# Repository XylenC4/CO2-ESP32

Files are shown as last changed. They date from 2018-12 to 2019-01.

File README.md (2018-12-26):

# CO2-ESP32
Arduino CO2 and Temperature logger based on BOSCH BME280 and Winsen MH-Z19B

## Functions
___
- Shows C02, Temperature, Humidity, Pressure
- Temperature (and humidity) can be corrected, if the BME280 if off calibration
- Thingspreak implementation including WiFi access

## Parts needed
___
- DOIT! ESP32 (any ESP32 should work, might not fit in the case)
- OLED 0.97" 128x64 Display
- MH-Z19B CO2 sensor
- BME280 sensor

    -> I'll had a 5V compatible version
    
    -> Make shure you connect it to 3.3V if you don't have

## Shematics
___
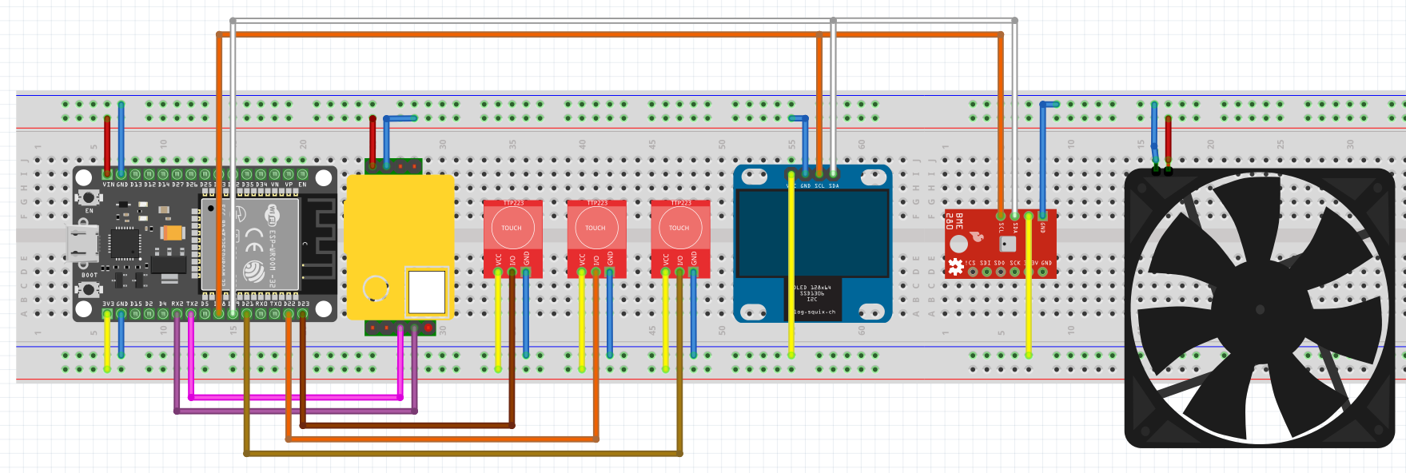
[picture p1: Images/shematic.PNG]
shematic


### User Interface
___
General Interface

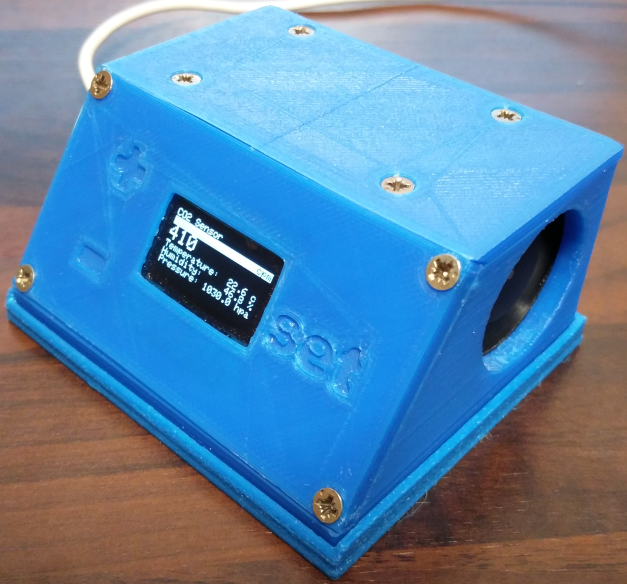
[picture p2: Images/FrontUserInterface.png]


### Log
___
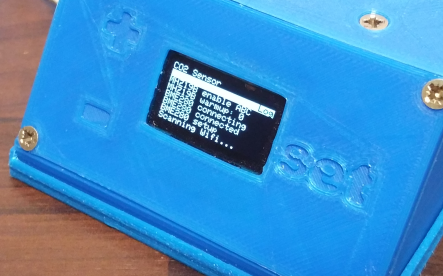
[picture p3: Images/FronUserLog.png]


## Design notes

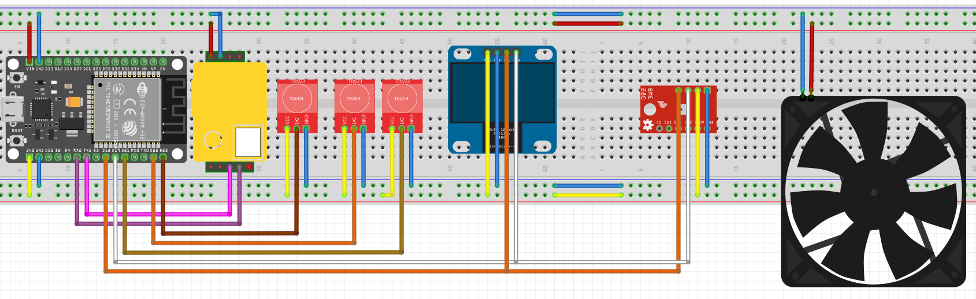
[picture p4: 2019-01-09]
Drawing/shematic.PNG

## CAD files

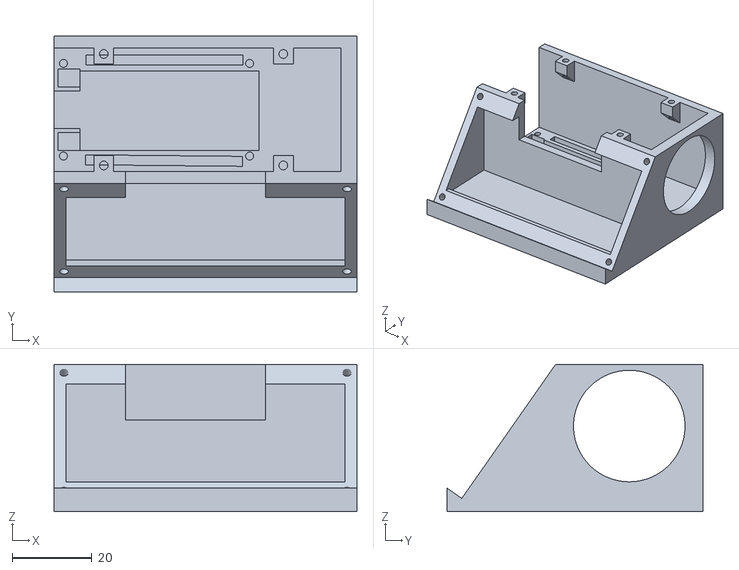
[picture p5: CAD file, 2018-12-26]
Drawing/ESP32.stl
76.1 x 64.3 x 37.0

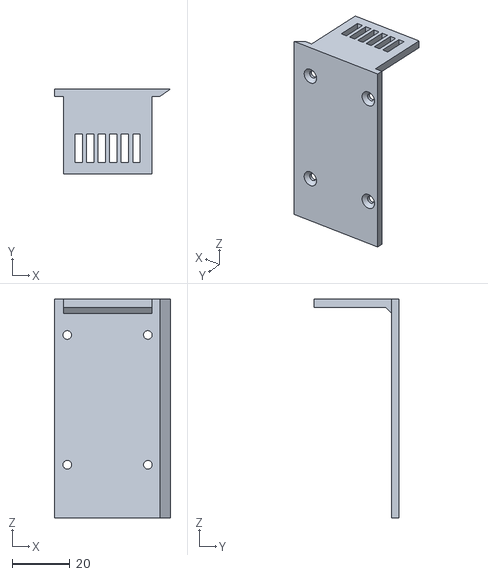
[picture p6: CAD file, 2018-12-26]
Drawing/Cover.stl
40.4 x 29.6 x 76.1

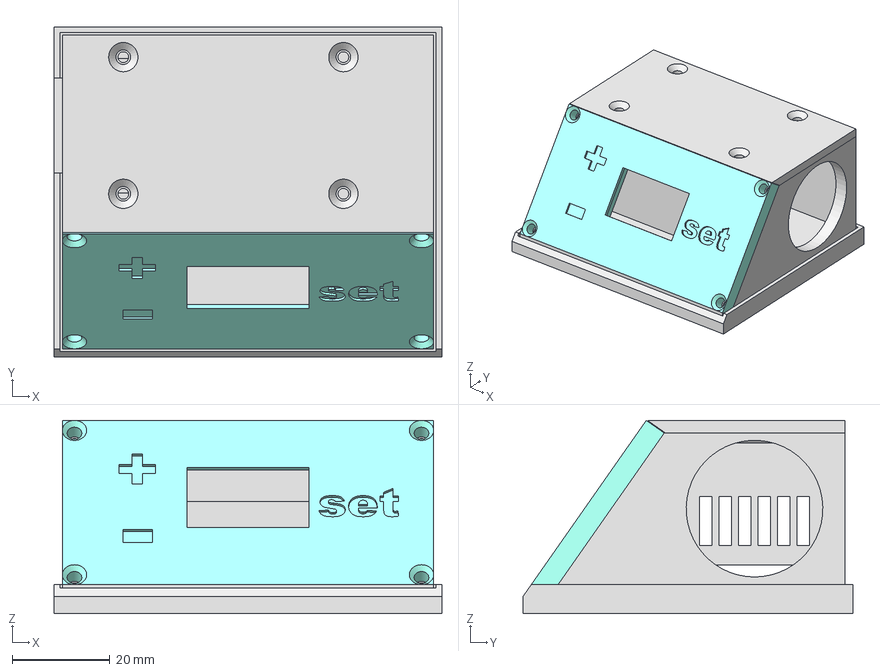
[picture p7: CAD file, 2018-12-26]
Drawing/Part.step
79.5 x 67.7 x 39.6 mm
ESP32
Case_base_v3
Cover
RubberCover

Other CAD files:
Drawing/Part.stl

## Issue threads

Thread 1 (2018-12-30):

Shema

Alfourbe, 2018-12-30:
Hi,
thank you fo sharing, I plan to make it and I ordered MHz19 sensor, meanwhile there is a little error in the schema, MHZ and OLED GND line are not connected to ground.

How do you power it? via USB?

Thanks

XylenC4, 2019-01-04:
Hey, yes USB power is good enough. I will check the "shematics" tomorrow. Thank you!

XylenC4, 2019-01-09:
i fixed it and some other things! Thanks you for your remarks.

Closed 2019-01-09.

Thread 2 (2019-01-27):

No much info

ffnull, 2019-01-27:
Hello. Im buy all needed components and print housing. But you doesnt provide much info. Withch libraries  to use? And other

XylenC4, 2019-01-27:
all of the used Arduino Libaries you can find on top of https://github.com/XylenC4/CO2-ESP32/blob/master/Arduino/CO2.ino

Adafruit_GFX
Adafruit_SSD1306
Adafruit_Sensor
Adafruit_Sensor

all the other are a part of the ESP32 Arduino enviroment.

ffnull, 2019-01-27:
D:\Downloads\CO2-ESP32-master\CO2-ESP32-master\Arduino\CO2\Thingspeak.ino: In function 'void loop_Thingspeak()':

D:\Downloads\CO2-ESP32-master\CO2-ESP32-master\Arduino\CO2\Thingspeak.ino:14:23: warning: unused variable 'SensorLoop' [-Wunused-variable]

   static unsigned int SensorLoop = 0;

                       ^

D:\Downloads\CO2-ESP32-master\CO2-ESP32-master\Arduino\CO2\TouchButton.ino: In function 'int CheckMenuOrder()':

TouchButton:46:1: error: no return statement in function returning non-void [-Werror=return-type]

 }

 ^

cc1plus.exe: some warnings being treated as errors

exit status 1
no return statement in function returning non-void [-Werror=return-type]

ffnull, 2019-01-27:
And. Please show the photo how you put everything inside.

XylenC4, 2019-01-27:
Make shure you have https://dl.espressif.com/dl/package_esp32_index.json inside the preferences and install "esp32" v1.0.0 or v1.0.1 at the board manager. Then you have to select the board "DOIT ESP32 DEVKIT V1"

Please try to rename the folder "Arduino" to "CO2" (which is the original name for the project)

XylenC4, 2019-01-27:
It's wired with 0.1 Header and soldered on the OLED & Touch Switches.
The sensors are glued with "hot snod".

https://github.com/XylenC4/CO2-ESP32/blob/master/Images/Wiring%201.jpg
https://github.com/XylenC4/CO2-ESP32/blob/master/Images/Wiring%202.jpg

ffnull, 2019-01-27:
All done. But still cant compile. Full log https://pastebin.com/0xugvqDd

XylenC4, 2019-01-27:
please update to Ardiono 1.8.8

ffnull, 2019-01-27:
When im compile CheckMenuOrder function. Its compiles

ffnull, 2019-01-27:
After flashing im got circle reboot with kernel panic

ffnull, 2019-01-27:
Please add zip archive with your libraries

XylenC4, 2019-01-27:
As requested: https://github.com/XylenC4/CO2-ESP32/tree/master/Arduino

ffnull, 2019-01-27:
Strange. My board esp32 core board v2. Your code still give kernel panic.
`Guru Meditation Error: Core  1 panic'ed (IntegerDivideByZero). Exception was unhandled.`
What can be wrong?

ffnull, 2019-01-27:
Any ideas?

XylenC4, 2019-01-27:
Because of some other projects with bluetooth i flashed a newer firmware (which helped with bluetooth) https://www.espressif.com/en/support/download/at

yours is "ESP32-WROVER" and can be flashed with https://github.com/espressif/esptool
On Windows you can use the esptool out of the Arduino Board Manager: %AppData%\..\Local\Arduino15\packages\esp32\tools\esptool_py\2.6.0

ffnull, 2019-01-31:
Hah. My chip is esp-wroom-32. going to flash correct firmware

ffnull, 2019-01-31:
Ok. Flash correct firmware. Then yours code. Still doesnt work

XylenC4, 2019-02-01:
you can try to compile it on another computer where Arduino never was installed.

Closed 2019-05-24.

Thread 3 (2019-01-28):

Question

Alfourbe, 2019-01-28:
Hi,
sorry to open an issue, I have just 2 questions but don not see how to ask without opening an issue.
I wonder if the fan could have an impact on the pressure reading in the box. Did you test with and without fan to check the difference?

I received my Mzh19 since, and I dont' want to keep the fan on all time. I will put a transistor to switch it on just one minute before reading co2 every 15-20 min, do you think it can be an issue with the reliability of co2 reading?
Thank you

Alfourbe, 2019-01-31:
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
FYI I finnally make it work, thanks to you, it was more complicated tha expected as I used parts I already have (ESP8266, BMP180... and I had to change and adapt all libraries but here we go
Happy :), thank to you

XylenC4, 2019-02-01:
nice to see you was able to run and modify it for ESP8266. I'll have some issues with a thermal drift which is caused by my ESP32. At the moment i do not use a deep sleep but this will be changed in the future. Have you done any tests regarding the pressure yet? There is no "warmup" time specified in the datasheet of the MH-Z19B.

Alfourbe, 2019-02-01:
HI, from l what I saw in the Datasheet, it is 3 min preheat time and response time less than 60sec, that's why I wanted to read pressure, switch on fan, wait 1 min, read CO2, and switch off fan.
I think I will also start WIFI only when connecting to Thingspeak, and switch it off the rest of time.
For pressure I get a reading with bmp180 but I don't have humidity so I ordered a BME280 and as I didn't print the enclosure yet, I didn't test if it have an impact on pressure reading.
I am surprised you have thermal drift with the Fan switch on, You can not move it away from ESP32?
I am also plan to add a BH1750 to dim the OLED, it is in my bedroom now and at night it is really too brightness. I will add a RGB led also to make a green/orange/red visual alert, and it will be dimm to with light sensor..
Your code is clear, and I like that you split for each component, that make easy to modify and adapt to my needs.
Let's wait for the material to arrive from aliexpress....

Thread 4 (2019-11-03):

.stl front face missing

jeffou66500, 2019-11-03:
Hello, sorry to disturb you.
Regarding the .stl files, would it be possible to have the file of the front face for the OLED display? I do not know how to undo the file with all the pieces hanging. (I already printed in 3D the rest of the pieces) Thank you in advance. Fabrice

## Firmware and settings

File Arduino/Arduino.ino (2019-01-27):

#include <Wire.h>
#include <SPI.h>
#include <Adafruit_GFX.h>
#include <Adafruit_SSD1306.h>
#include <Adafruit_BME280.h>
#include <HardwareSerial.h>

/*********************************************************************
  General
*********************************************************************/
extern void OledDisplayLogAdd(String sValue, int iDelay);
extern unsigned int ppm;

#define PROJECT_NAME "CO2 Sensor"
#define DELAY_TIME 100
#define STARTUP_TIME 3

/*********************************************************************
  Wifi / Thingspeak
*********************************************************************/
const char* ssid     = ""; // Your SSID (Name of your WiFi)
const char* password = ""; //Your Wifi password

const char* host = "api.thingspeak.com";
String api_key = ""; // Your API Key provied by thingspeak

#define DELAY_TIME_BETWEEN_THINGSPEAK_UPDATE 10*60 // 10min

/*********************************************************************
  Monochrome OLEDs based on SSD1306 drivers
*********************************************************************/
#define OLED_RESET 13
Adafruit_SSD1306 display(OLED_RESET);

#if (SSD1306_LCDHEIGHT != 64)
#error("Height incorrect, please fix Adafruit_SSD1306.h!");
#endif

/*********************************************************************
  Touch-Sensors
*********************************************************************/
#define TOUCH_PLUS 21
#define TOUCH_MINUS 22
#define TOUCH_SET 23

/*********************************************************************
  BME280 Sensor Data
*********************************************************************/
#define COMPENSATION_TEMP -3
#define DELAY_TIME_BETWEEN_BME280_UPDATE 30 // in s
extern float fBME280Temperature, fBME280Pressure, fBME280Humidity, fBME280AbsoluteHumidity, fBME280CorrectedRelativeHumidity;
extern float fBME280OriginalTemperature, fBME280OriginalHumidity, fBME280OriginalPressure;

/*********************************************************************
  MHZ19B CO2 Sensor Data
*********************************************************************/
#define WARMUP_TIME 5
#define DELAY_TIME_BETWEEN_MHZ19B_UPDATE 60 // in s
extern unsigned int uiCo2Ppm,uiCo2Temp,uiCo2UhUl,uiCo2state;

/*********************************************************************
  Main loop
*********************************************************************/
void setup() {
  Serial.begin(9600);
  Wire.begin(18,19);
  setup_OLED();
  OledDisplayLogClear();
  OledDisplayLogWhait("Startup delay", STARTUP_TIME);
  setup_MHZ19B();
  OledDisplayLogWhait("MHZ19B warmup", WARMUP_TIME);
  setup_BME280();

  loop_MHZ19B();
  loop_BME280();
  loop_Touch();
  setup_Thingspeak();
  showDisplay();
}


void loop() {
 loop_MHZ19B();
 loop_BME280();
 showDisplay();
 loop_Thingspeak();
 loop_Touch();  
}

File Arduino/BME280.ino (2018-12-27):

/***************************************************************************
  This is a library for the BME280 humidity, temperature & pressure sensor

  Designed specifically to work with the Adafruit BME280 Breakout
  ----> http://www.adafruit.com/products/2650

  These sensors use I2C or SPI to communicate, 2 or 4 pins are required
  to interface. The device's I2C address is either 0x76 or 0x77.

  Adafruit invests time and resources providing this open source code,
  please support Adafruit andopen-source hardware by purchasing products
  from Adafruit!

  Written by Limor Fried & Kevin Townsend for Adafruit Industries.
  BSD license, all text above must be included in any redistribution
 ***************************************************************************/

Adafruit_BME280 bme; // I2C

float fBME280Temperature, fBME280Pressure, fBME280Humidity, fBME280AbsoluteHumidity, fBME280CorrectedRelativeHumidity;
float fBME280OriginalTemperature, fBME280OriginalHumidity, fBME280OriginalPressure;
unsigned long lBME280LoopPreviousTime = 0;

void setup_BME280() {
    bool status;
    
    OledDisplayLogAdd("BME280 connecting", 0);
    status = bme.begin();  
    if (!status) {
        OledDisplayLogAdd("BME280 not found", 0);
        OledDisplayLogAdd("check wiring!", 5000);
        ESP.restart();
    }
    OledDisplayLogAdd("BME280 connected", 0);
    OledDisplayLogAdd("BME280 setup", 100);
    bme.setSampling(Adafruit_BME280::MODE_FORCED,
                    Adafruit_BME280::SAMPLING_X1,   // temperature
                    Adafruit_BME280::SAMPLING_X1, // pressure
                    Adafruit_BME280::SAMPLING_X1,   // humidity
                    Adafruit_BME280::FILTER_OFF );   
  // Set Time
  lBME280LoopPreviousTime = millis();                
}

void loop_BME280() { 
  unsigned long lLoopActual = millis();
  unsigned long lLoopDelayTime = (lLoopActual - lBME280LoopPreviousTime) / 1000;

  if(lLoopDelayTime > DELAY_TIME_BETWEEN_BME280_UPDATE) {
    OledDisplayLogAdd("BME280 Update", 0);
    lBME280LoopPreviousTime = millis();
    bme.takeForcedMeasurement(); // has no effect in normal mode
    //Uncompensated values from sensor
    fBME280OriginalTemperature = bme.readTemperature();
    fBME280OriginalPressure = bme.readPressure() / 100.0F;
    fBME280OriginalHumidity = bme.readHumidity();
    fBME280AbsoluteHumidity = getAbsoluteHumidity(fBME280OriginalHumidity, fBME280OriginalTemperature);
 
    //Compensation if neccessarily
    if(COMPENSATION_TEMP != 0) {
      fBME280Temperature = fBME280OriginalTemperature + COMPENSATION_TEMP;
      fBME280Pressure = fBME280OriginalPressure;
      fBME280Humidity = getRelativeHumidity(fBME280AbsoluteHumidity, fBME280Temperature, fBME280Pressure);
    }
    else {
      fBME280Temperature = fBME280OriginalTemperature;
      fBME280Pressure = fBME280OriginalPressure;
      fBME280Humidity = fBME280OriginalHumidity;
    }
  }
}

//https://forum.arduino.cc/index.php?topic=420975.0
float getAbsoluteHumidity(float Humidity, float Temperature ) {
  return (6.112 * pow(2.71828,((17.67 * Temperature)/(Temperature + 243.5))) * Humidity * 2.1674) / (273.15 + Temperature)/1000; // in g/m^3
}

//https://planetcalc.com/2167/
float getRelativeHumidity(float AbsoluteHumidity, float Temperature, float Pressure) {
  float A = AbsoluteHumidity;
  float tp = Pressure;
  float t = Temperature;
  float et = 6.112*exp((17.62*t)/(243.12+t));
  float fp = 1.0016 + 3.15 * pow(10,-6) * tp - 0.074/tp;
  float trh = (A*461.5*(t + 273.15))/(fp*et);
  return trh;
}
